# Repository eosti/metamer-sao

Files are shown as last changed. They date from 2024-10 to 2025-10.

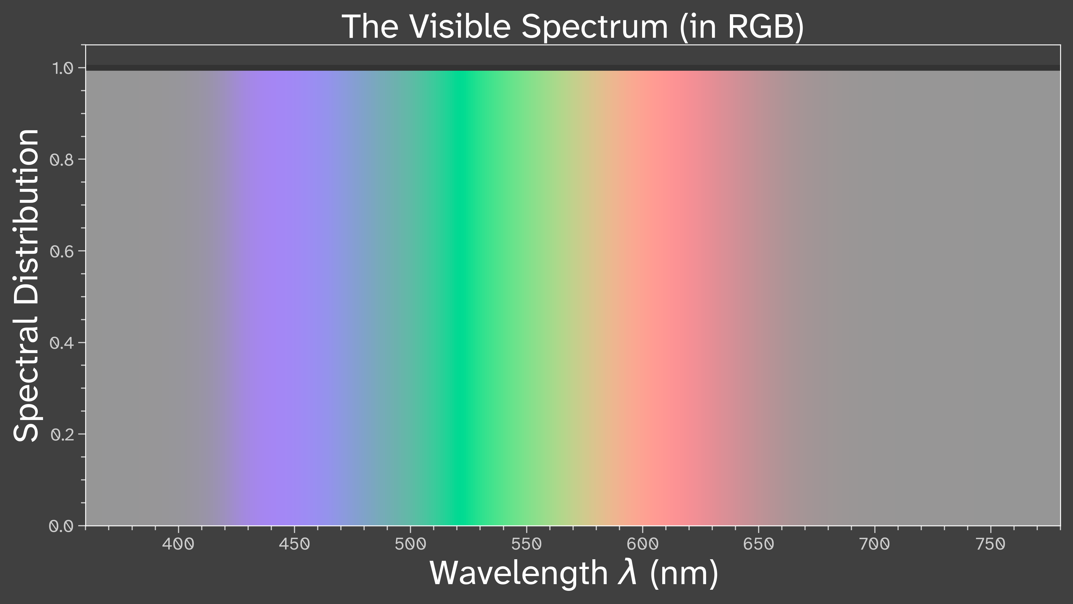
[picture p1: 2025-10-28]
python_graphs/visible_spectrum.png

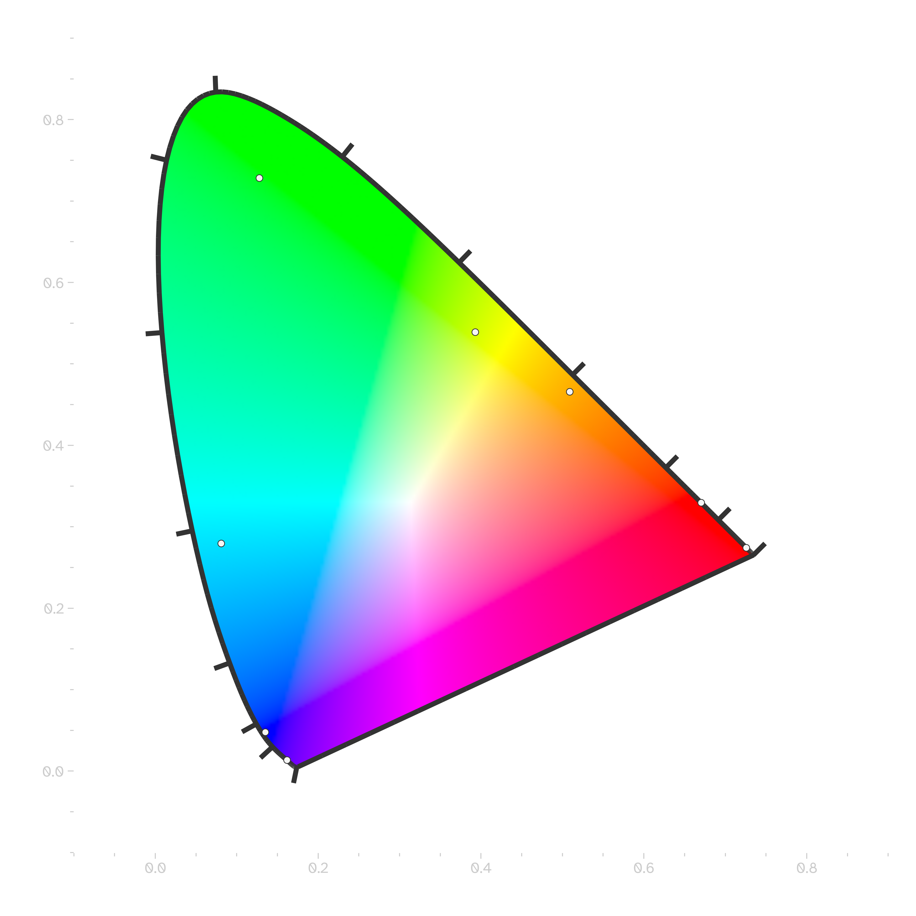
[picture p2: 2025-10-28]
python_graphs/build_cie1931.png

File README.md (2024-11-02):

# Metamer SAO
A collection of files related to the [Metamer SAO](https://reidsoxharris.me/projects/metamer-sao)

The `schematics` directory has PDFs of the schematics, the `board-files` directory has all the files you might need for fabrication and assembly including a BOM, and the `generators` directory contains the code used for auto-generating code for doing things like normalizing brightness. 

Some MicroPython code that you can run on the badge is found in the `micropython` directory. 
The code used on the PY32F002B MCU used to bootstrap I2C is in the `py32` directory, and current builds are in `py32/releases`.

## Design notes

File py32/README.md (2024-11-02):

# PY32
This is the code use for the bootstrap I2C MCU. 
It's the PY32F002B, so the cheapest one possible. 

The structure of the repo is largely taken from [py32f0-template](https://github.com/IOsetting/py32f0-template) -- I still don't know how Makefiles work, and that's okay. 
Building is as easy as `make`.

The version of the MCU code is stored in register 0x86. 

### Known Issues
On v0 firmware, the driver will be unable to communicate on I2C due to the MCU assuming the same address as the driver. 
In v1, the MCU will not only disable its own address, but also deinit the I2C peripheral after sending it's packet.
Problem solved!

The MCU will send a burst of I2C packets right at boot thay may conflict with other goings-ons on the bus. 
Theoretically, this should occur before the Pico on the badge is able to boot, but it's a shared bus and it's not the most considerate to other users on the bus to unexpectedly have a multi-master situation. 
If you run into any issues, a workaround is to cut off the I2C pins on the SAO connector: the SAO will still turn on as expected, but will not be controllable from the badge (obviously).

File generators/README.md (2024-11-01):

# Generators
i.e. code that generates other code! 

## generate_default_values
Quick script that parses a YAML file of LED specs and tries to come up with a normalizing array such that the brightness are the same. 

Emphasis on _tries_.
At present it assumes brightness scales with current (it does not) and that humans percieve all colors the same (we do not). 
But hey, it gets 95% of the way there, so that's good enough.

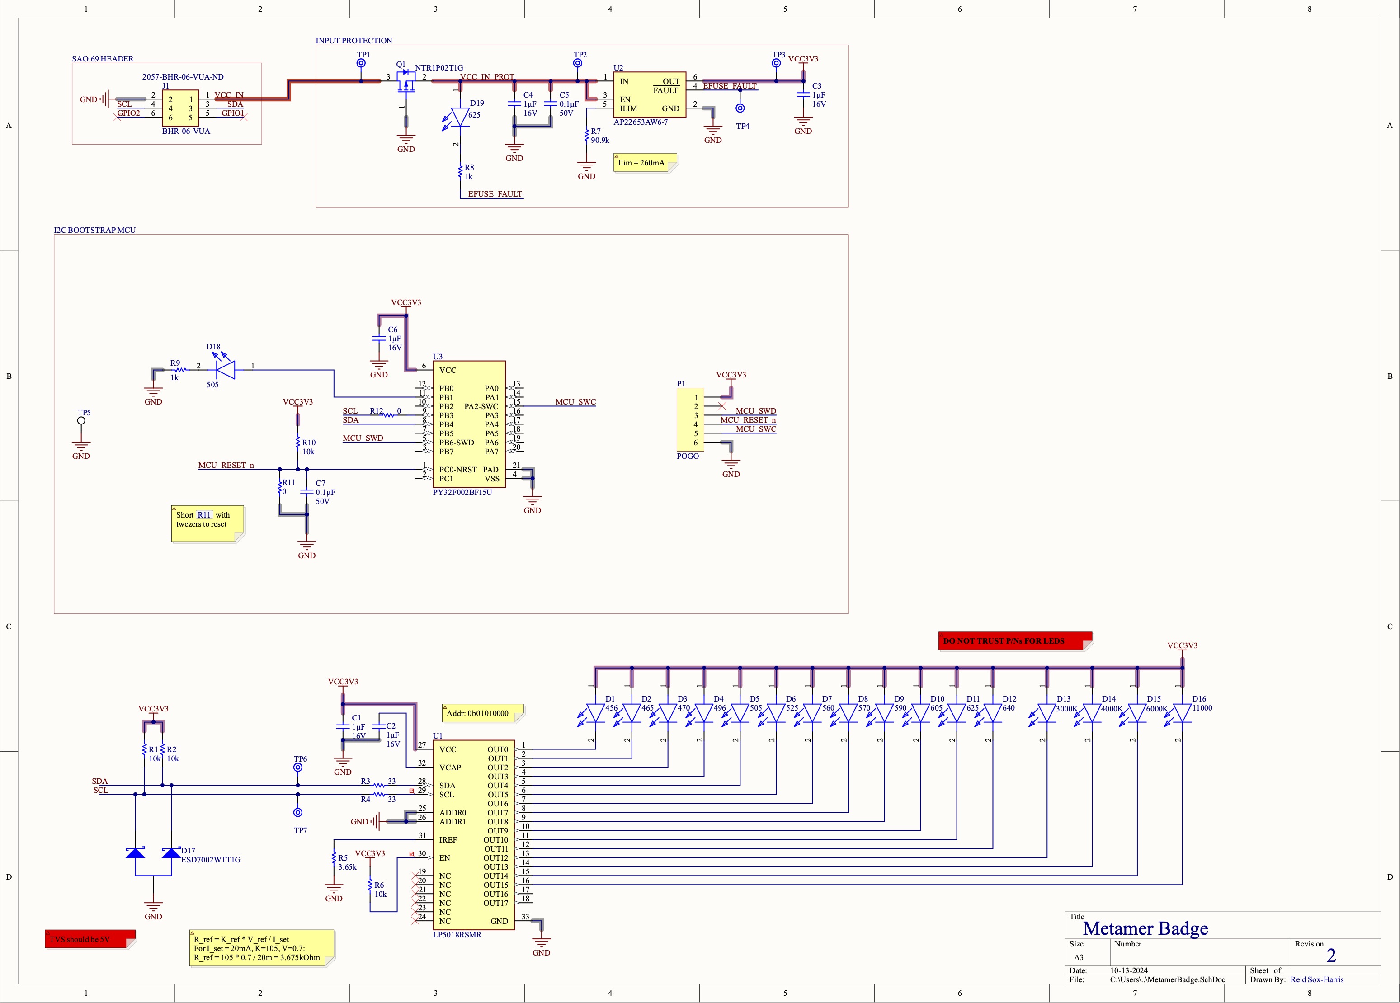
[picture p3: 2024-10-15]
schematics/metamerv2.jpg

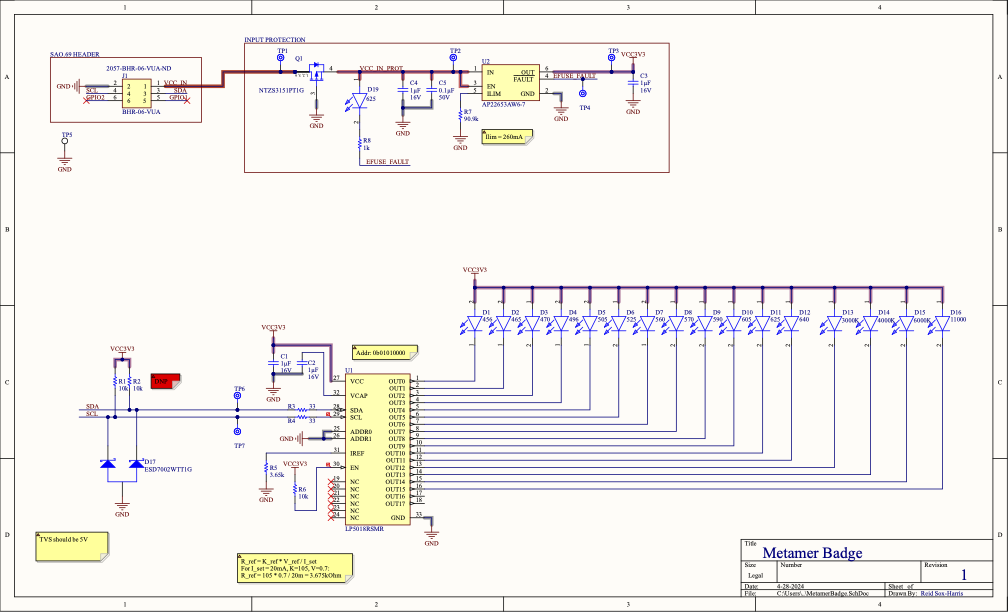
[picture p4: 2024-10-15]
schematics/Metamerv1.png

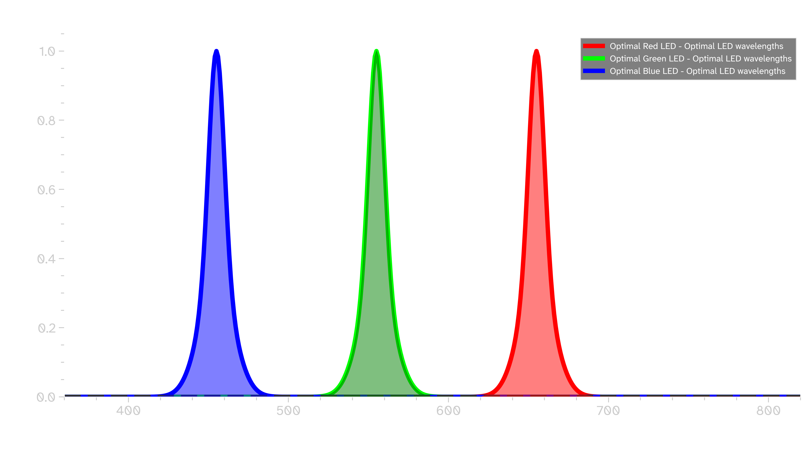
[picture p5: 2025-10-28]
python_graphs/ideal_leds.png

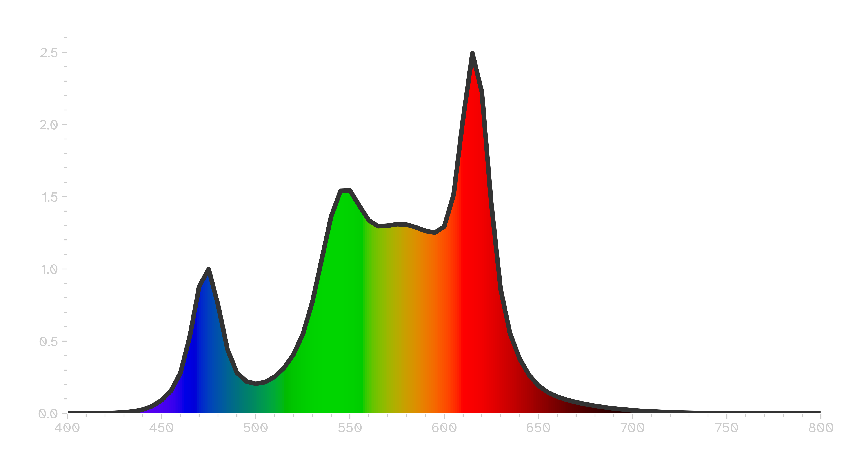
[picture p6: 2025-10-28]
python_graphs/lime_illuminant.png

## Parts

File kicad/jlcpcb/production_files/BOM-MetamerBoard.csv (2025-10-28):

Comment | Designator | Footprint | LCSC | Quantity
CGA3E1X7R1C105M080AC | C1,C2,C5 | C_0603 | C1588 | 3
CGA3E2X7R1H104K080AE | C4,C7 | C_0603 | C14663 | 2
CRCW060310K0FKEC | R1,R10,R2,R6,R7 | R_0603 | C25804 | 5
CRCW060333R0FKEA | R3,R4 | R_0603 | C23140 | 2
CRCW06033K65FKEA | R5 | R_0603 | C22980 | 1
ERJ-3EKF1001V | R9 | R_0603 | C21190 | 1
ERJ-3GEY0R00V | R11,R12,R8 | R_0603 | C21189 | 3
ESD7002WTT1G | D17 | SOT-23-3_L2.9-W1.5-P1.90-LS2.6-BR | C20615823 | 1
LP5018RSMR | U1 | FP-RSM0032B-MFG | C2891574 | 1
PY32F002BF15U | U3 | QFN-20-1EP_3x3mm_P0.4mm_EP1.65x1.65mm | C7469099 | 1
QBLP631-R | D18 | LED_0603_1608Metric_Pad1.05x0.95mm_HandSolder_SmallSilk | C2286 | 1
~ | C6 | C_0402 | C307331 | 1
~ | U2,U4 | SOT-363_SC-70-6 | C38663 | 2
QBLP661-IW5-CW | D16 | LED_0805_2012Metric_Pad1.15x1.40mm_HandSolder_SmallSilk |  | 1
QBLP631-S3 | D12 | LED_0805_2012Metric_Pad1.15x1.40mm_HandSolder_SmallSilk |  | 1
QBLP631-R | D11 | LED_0805_2012Metric_Pad1.15x1.40mm_HandSolder_SmallSilk |  | 1
QBLP631-O | D10 | LED_0805_2012Metric_Pad1.15x1.40mm_HandSolder_SmallSilk |  | 1
QBLP631-Y | D9 | LED_0805_2012Metric_Pad1.15x1.40mm_HandSolder_SmallSilk |  | 1
QBLP631-AG | D8 | LED_0805_2012Metric_Pad1.15x1.40mm_HandSolder_SmallSilk |  | 1
~ | D7 | LED_0805_2012Metric_Pad1.15x1.40mm_HandSolder_SmallSilk |  | 1
QBLP631-IG | D6 | LED_0805_2012Metric_Pad1.15x1.40mm_HandSolder_SmallSilk |  | 1
QBLP631-IB | D5 | LED_0603_1608Metric_Pad1.05x0.95mm_HandSolder_SmallSilk |  | 1
QBLP631-IB | D4 | LED_0603_1608Metric_Pad1.05x0.95mm_HandSolder_SmallSilk |  | 1
QBLP631-IB | D3 | LED_0805_2012Metric_Pad1.15x1.40mm_HandSolder_SmallSilk |  | 1
QBLP631-IB | D2 | LED_0805_2012Metric_Pad1.15x1.40mm_HandSolder_SmallSilk |  | 1
QBLP631-IB | D1 | LED_0805_2012Metric_Pad1.15x1.40mm_HandSolder_SmallSilk |  | 1
QBLP675-IW-NW | D14 | LED_SMD3012 |  | 1
QBLP675-IW-CW | D15 | LED_SMD3012 |  | 1
QBLP675-IW-WW | D13 | LED_SMD3012 |  | 1
BHR-06-VUA | J1 | SHDR6W64P254_2X3_1522X880X920P |  | 1

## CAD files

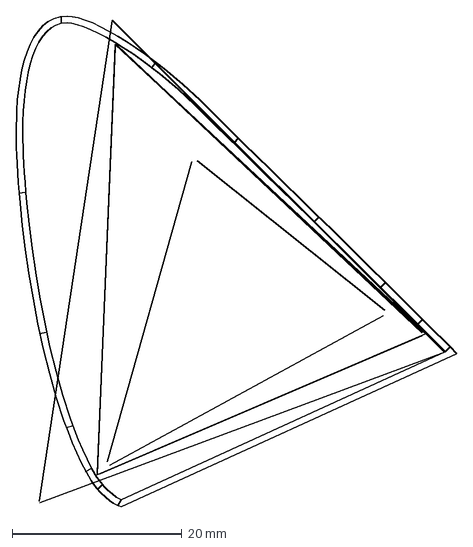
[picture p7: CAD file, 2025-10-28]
kicad/graphics/boardout.dxf
51.9 x 57.8 mm

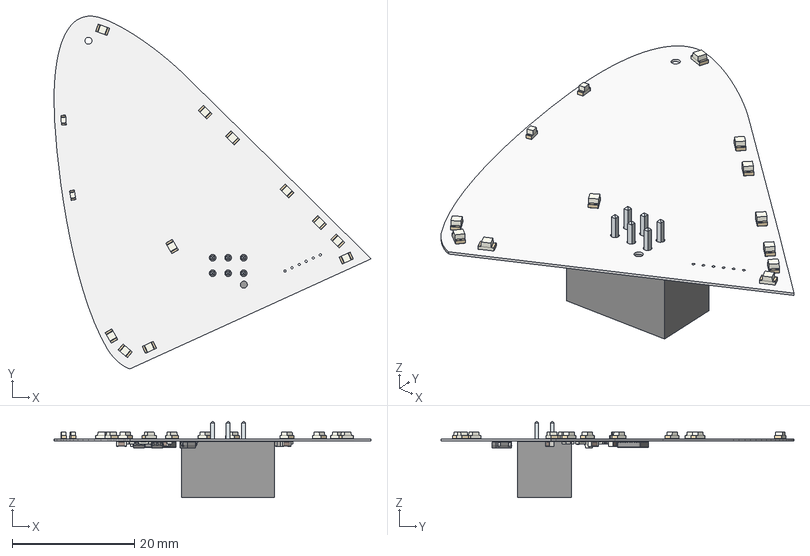
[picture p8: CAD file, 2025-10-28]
kicad/OUTPUTS/DOCS/.step
51.9 x 57.8 x 12.5 mm
LED_0603_1608Metric x 3
LED_0805_2012Metric x 11
C_0603 x 5
C_0402
R_0603 x 12
SOT-23-3_L2.9-W1.5-P1.90-LS2.6-BR
LeadsArray
SOT-363_SC-70-6 x 2
BODY-QFN
FRAME-RSM0032B
Texas Logo
Texas Logo - 1
MetamerBoard_PCB

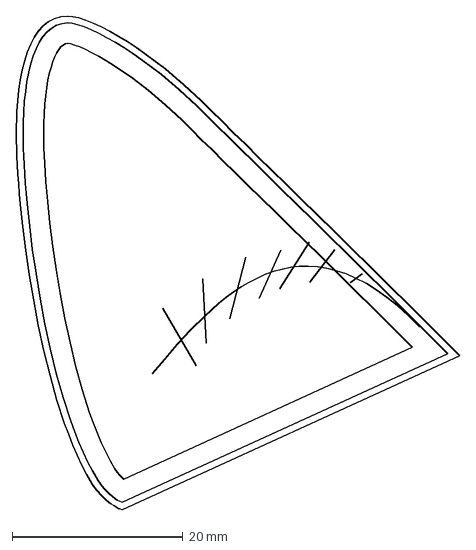
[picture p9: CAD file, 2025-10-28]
kicad/graphics/cie.dxf
51.9 x 57.8 mm

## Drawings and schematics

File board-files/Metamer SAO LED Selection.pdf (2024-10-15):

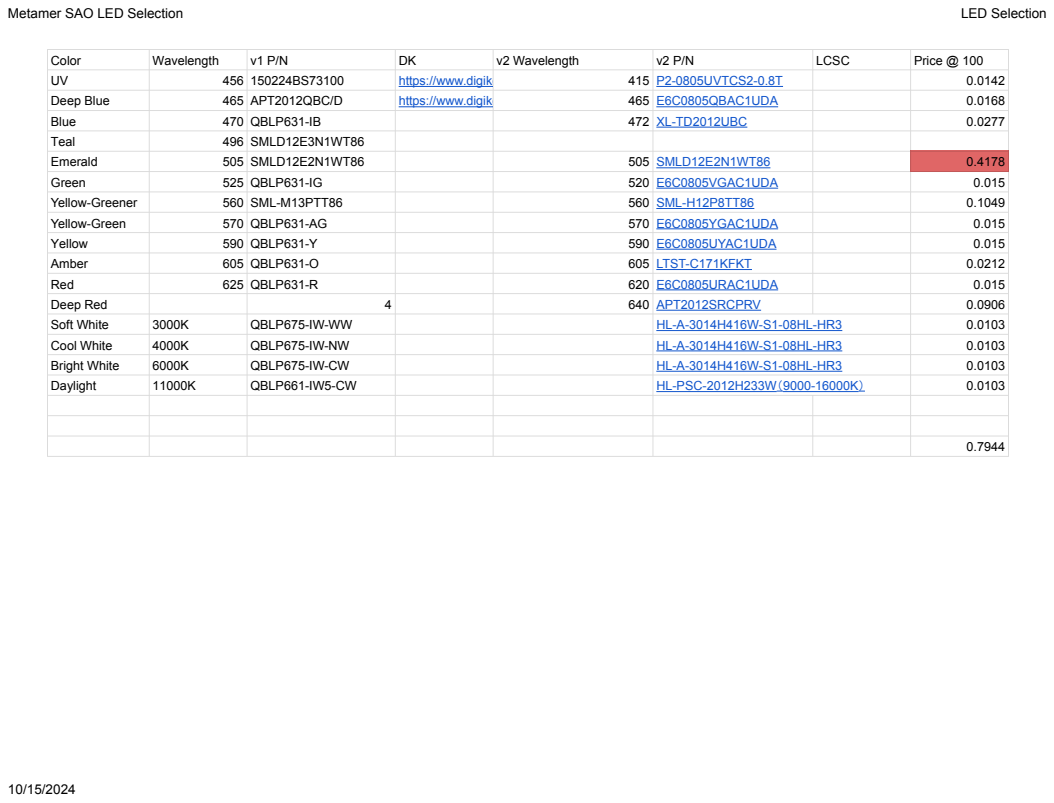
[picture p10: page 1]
Metamer SAO LED Selection; LED Selection; Color; Wavelength; v2 Wavelength; LCSC; Price @ 100; https://www.digikey.ca/en/products/detail/w%C3%BCrth-elektronik/150224BS73100/7315733 415 P2-0805UVTCS2-0.8T; Deep Blue; 465 APT2012QBC/D; https://www.digikey.ca/en/products/detail/kingbright/APT2012QBC-D/2163700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 465 E6C0805QBAC1UDA; Blue; 470 QBLP631-IB; 472 XL-TD2012UBC; Teal; 496 SMLD12E3N1WT86; Emerald; 505 SMLD12E2N1WT86; Green; 525 QBLP631-IG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

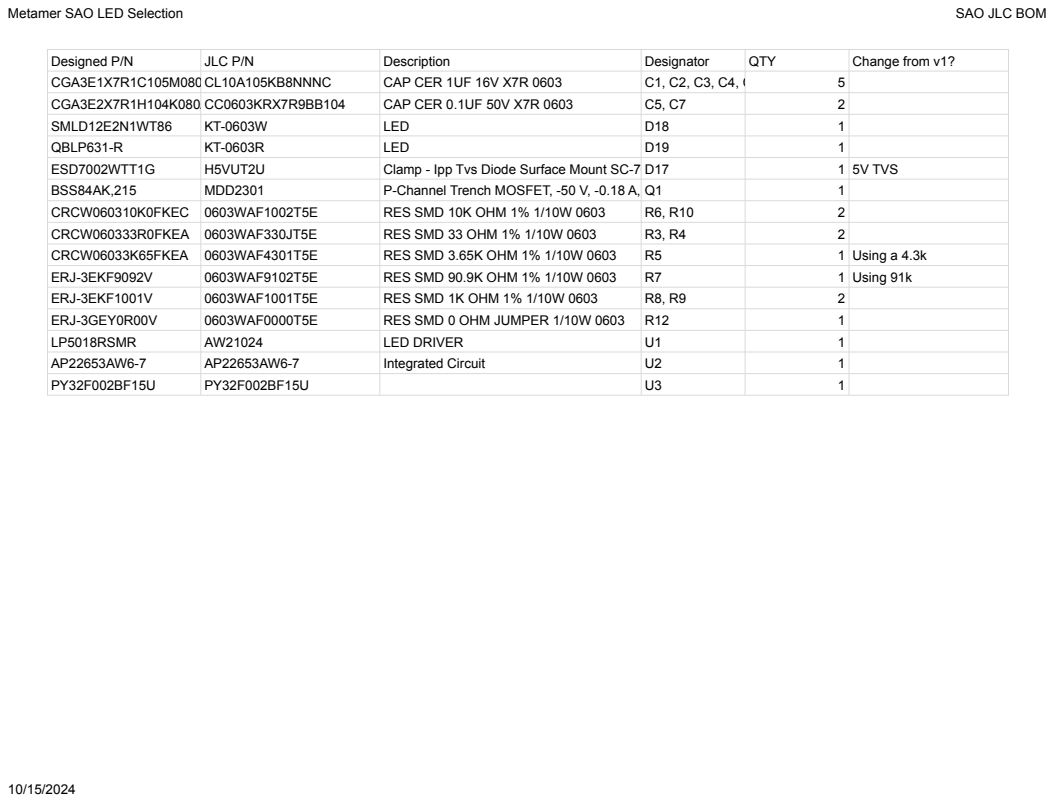
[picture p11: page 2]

Metamer SAO LED Selection | Debug Header

https://www.lcsc.com/product-detail/Pin-Headers_Samtec-FTSH-107-01-L-DV-K_C5307809.html

https://www.adafruit.com/product/2430#technical-details

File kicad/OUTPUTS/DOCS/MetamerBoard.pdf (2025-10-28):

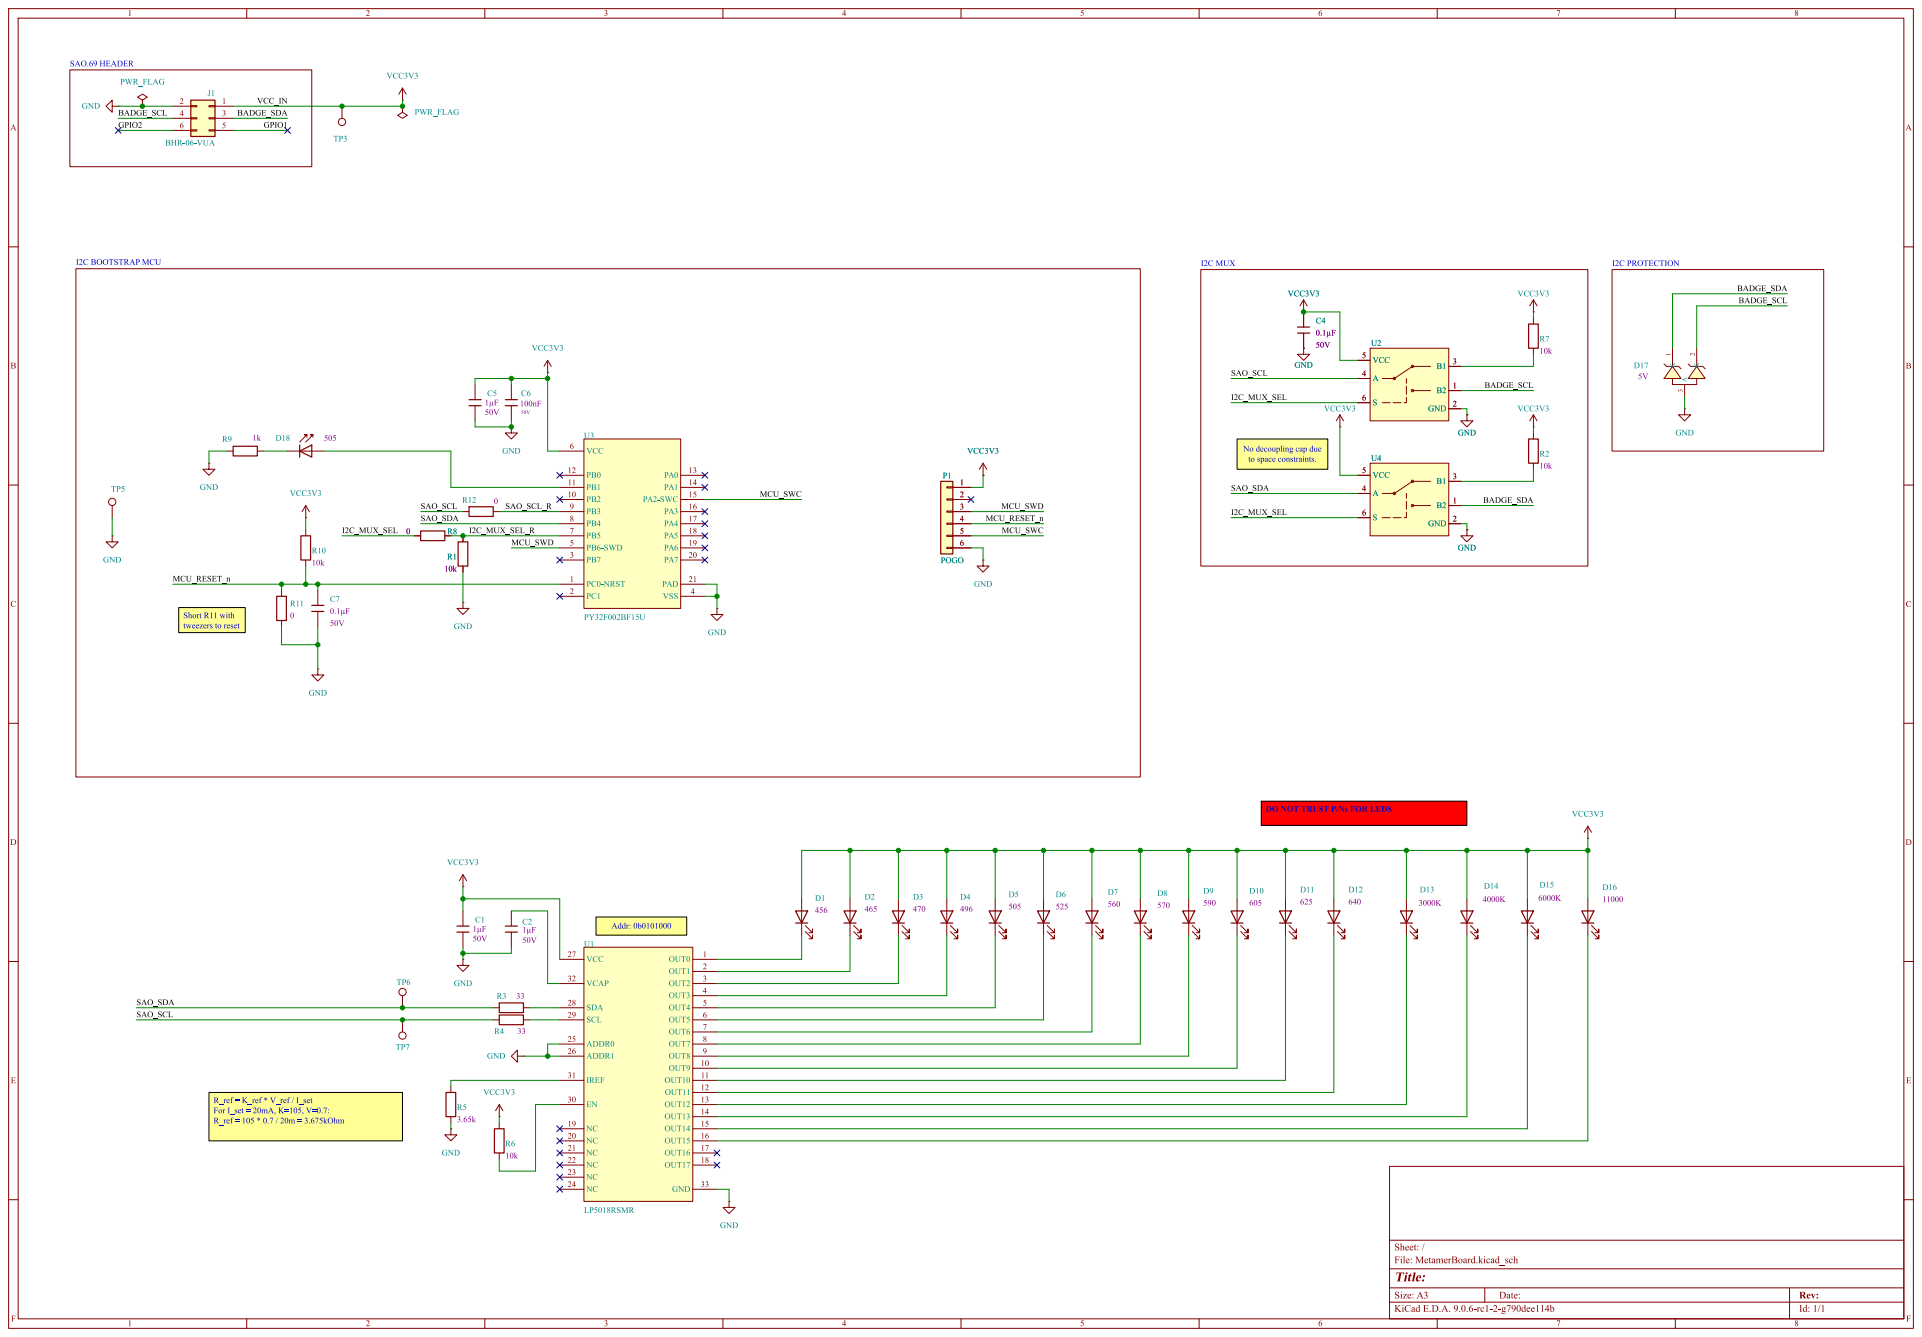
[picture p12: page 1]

10k VCC3V3 R7
to spaceconstraints. DO NOT TRUST P/NsFOR LEDS

Id: 1/1 Title: File: MetamerBoard.kicad_sch Sheet:/ GND

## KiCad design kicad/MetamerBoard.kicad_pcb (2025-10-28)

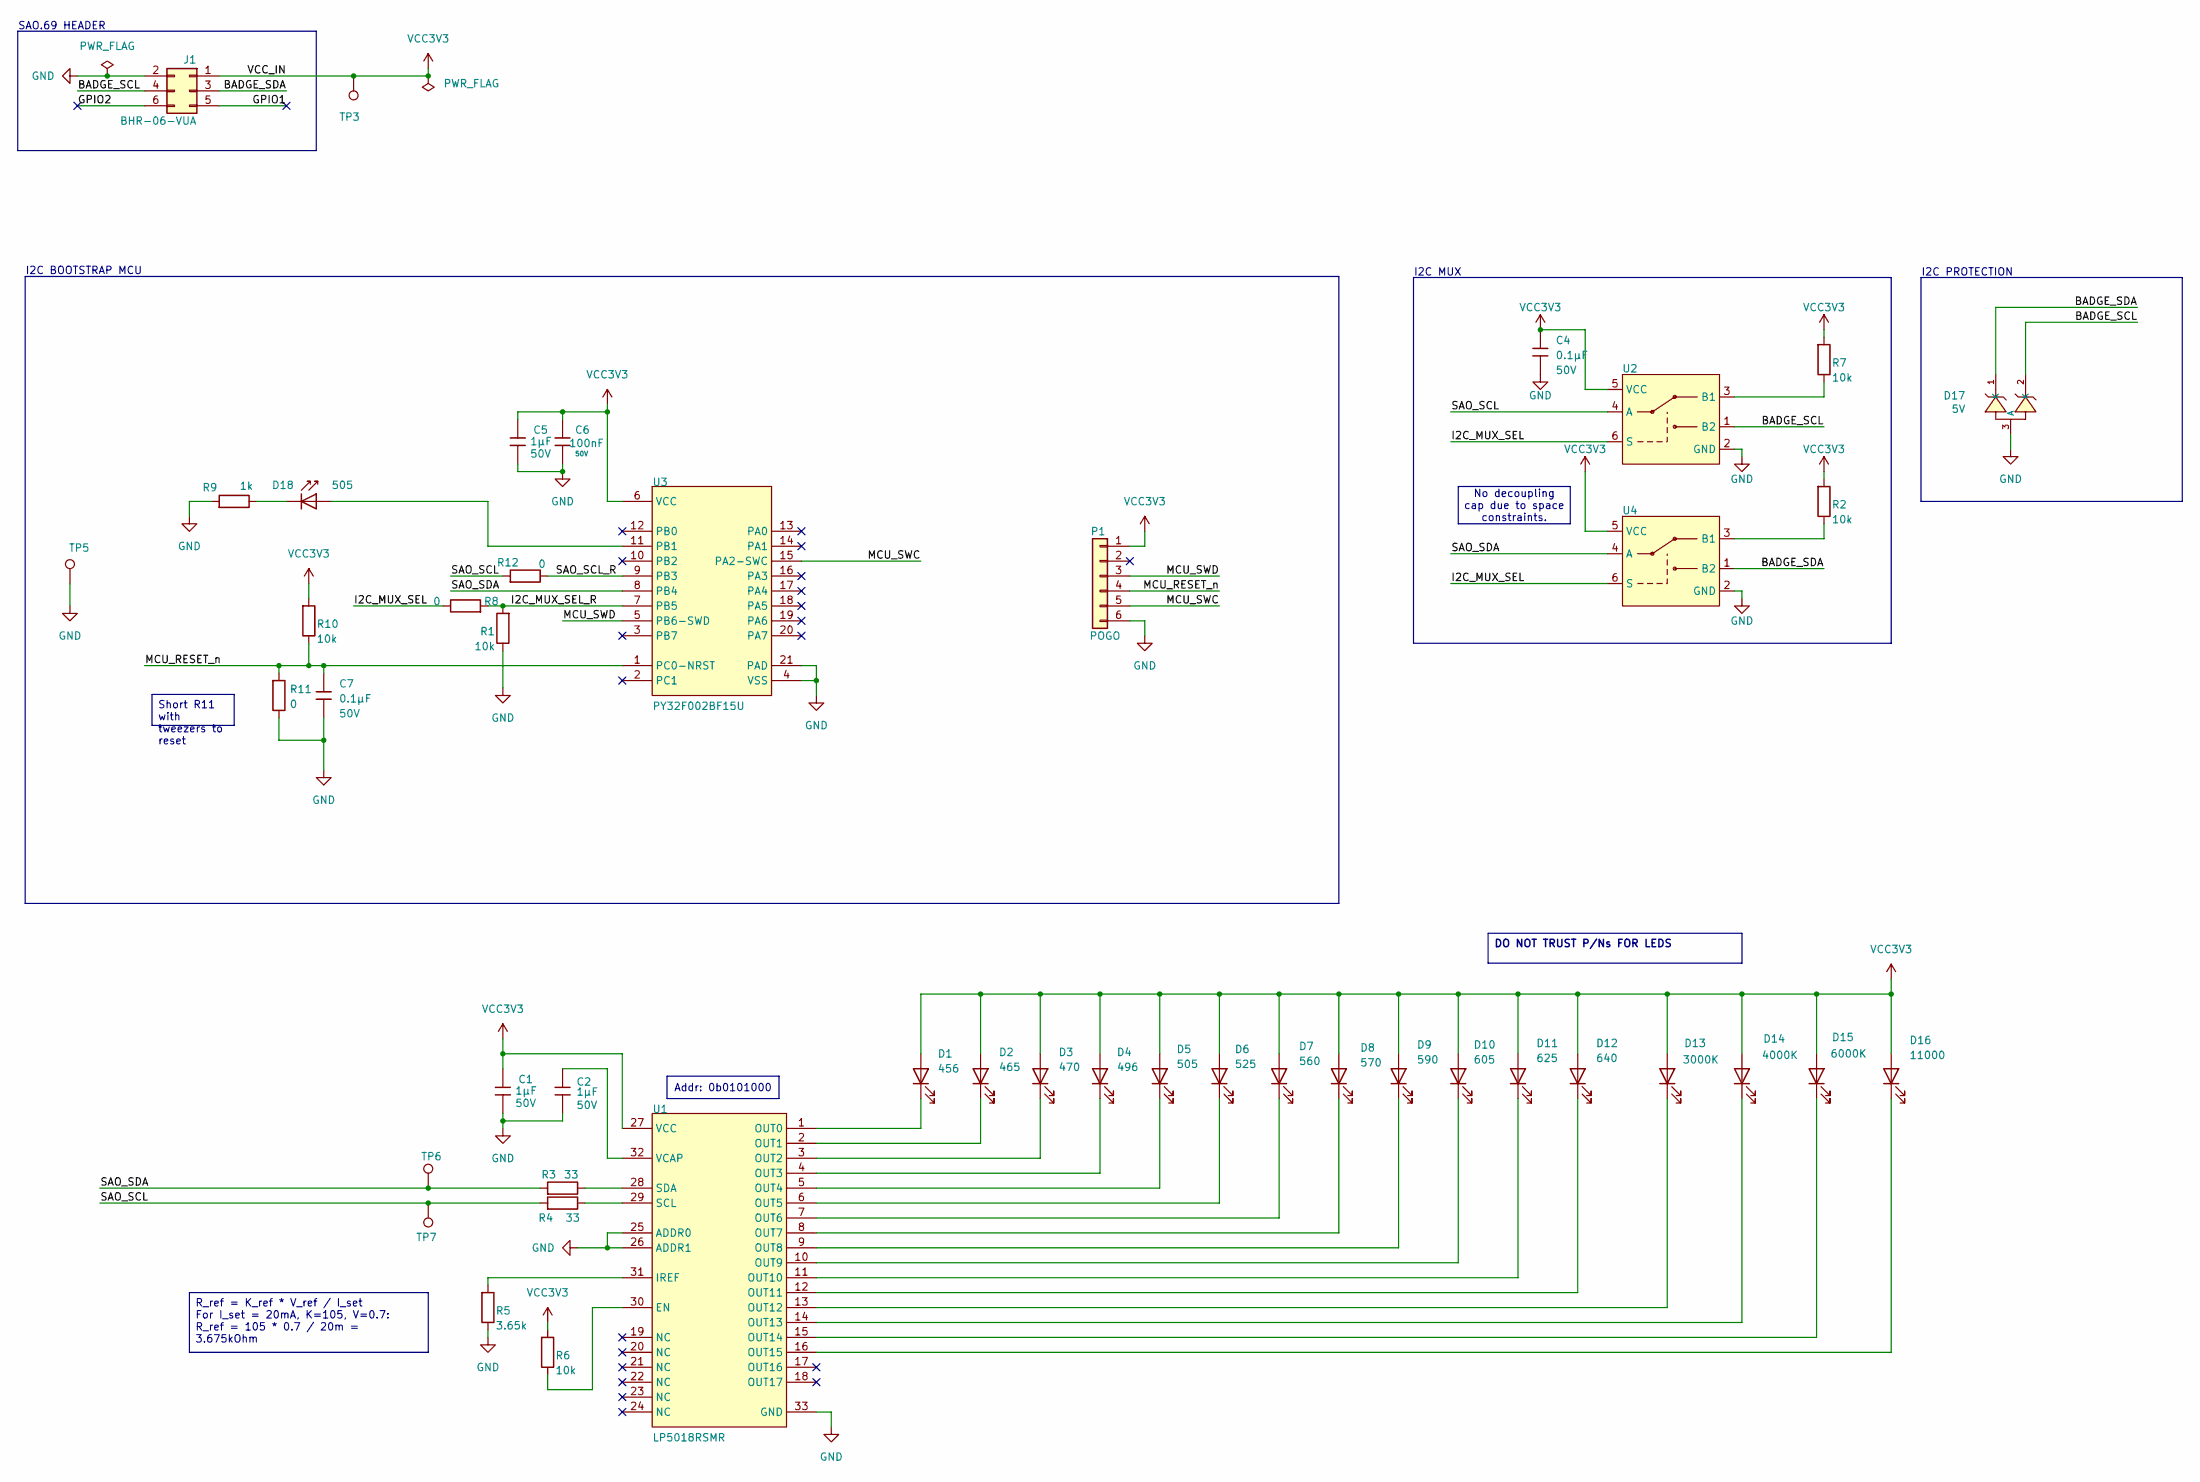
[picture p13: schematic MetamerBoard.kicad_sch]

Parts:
C1, C2, C5: CGA3E1X7R1C105M080AC; C_0603; TOLERANCE ±20%; RATINGS AEC-Q200; Part CL10B102KB8NNNC; LCSC C1588
C4, C7: CGA3E2X7R1H104K080AE; C_0603; TOLERANCE ±10%; VOLTAGE - RATED 50V; Part CC0603KRX7R9BB104; LCSC C14663
C6: C_0402; TOLERANCE ±20%; RATINGS AEC-Q200; Part CL05B104KB54PNC; LCSC C307331
D1, D2, D3: QBLP631-IB; LED_0805_2012Metric_Pad1.15x1.40mm_HandSolder_SmallSilk; MANUFACTURER_PART_NUMBER QBLP631-S3
D4, D5: QBLP631-IB; LED_0603_1608Metric_Pad1.05x0.95mm_HandSolder_SmallSilk; MANUFACTURER_PART_NUMBER QBLP631-S3
D6: QBLP631-IG; LED_0805_2012Metric_Pad1.15x1.40mm_HandSolder_SmallSilk; MANUFACTURER_PART_NUMBER QBLP631-S3
D7: LED_0805_2012Metric_Pad1.15x1.40mm_HandSolder_SmallSilk; MANUFACTURER_PART_NUMBER QBLP631-S3
D8: QBLP631-AG; LED_0805_2012Metric_Pad1.15x1.40mm_HandSolder_SmallSilk; MANUFACTURER_PART_NUMBER QBLP631-S3
D9: QBLP631-Y; LED_0805_2012Metric_Pad1.15x1.40mm_HandSolder_SmallSilk; MANUFACTURER_PART_NUMBER QBLP631-S3
D10: QBLP631-O; LED_0805_2012Metric_Pad1.15x1.40mm_HandSolder_SmallSilk
D11: QBLP631-R; LED_0805_2012Metric_Pad1.15x1.40mm_HandSolder_SmallSilk
D12: QBLP631-S3; LED_0805_2012Metric_Pad1.15x1.40mm_HandSolder_SmallSilk; MANUFACTURER_PART_NUMBER QBLP631-S3
D13: QBLP675-IW-WW; LED_SMD3012
D14: QBLP675-IW-NW; LED_SMD3012
D15: QBLP675-IW-CW; LED_SMD3012
D16: QBLP661-IW5-CW; LED_0805_2012Metric_Pad1.15x1.40mm_HandSolder_SmallSilk
D17: H5VHT2U; SOT-23-3_L2.9-W1.5-P1.90-LS2.6-BR; VOLTAGE - BREAKDOWN MIN 16.5V; VOLTAGE - REVERSE STAND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 5V; Part H5VHT2U; LCSC C20615823
D18: QBLP631-R; LED_0603_1608Metric_Pad1.05x0.95mm_HandSolder_SmallSilk; Part KT-0603R; LCSC C2286
J1: BHR-06-VUA; PinHeader_2x03_P2.54mm_Vertical; MANUFACTURER_PART_NUMBER BHR-06-VUA
P1: POGO; 6_Pin_POGO
R1, R2, R6, R7, R10: CRCW060310K0FKEC; R_0603; RATINGS AEC-Q200; TOLERANCE ±1%; Part 0603WAF1002T5E; LCSC C25804
R3, R4: CRCW060333R0FKEA; R_0603; RATINGS AEC-Q200; TOLERANCE ±1%; Part 0603WAF330JT5E; LCSC C23140
R5: CRCW06033K65FKEA; R_0603; TOLERANCE ±1%; RATINGS AEC-Q200; Part 0603WAF3601T5E; LCSC C22980
R8, R11, R12: ERJ-3GEY0R00V; R_0603; RATINGS AEC-Q200; TOLERANCE Jumper; Part 0603WAF0000T5E; LCSC C21189
R9: ERJ-3EKF1001V; R_0603; RATINGS AEC-Q200; TOLERANCE ±1%; Part 0603WAF1001T5E; LCSC C21190
TP3, TP6, TP7: TPAD10R; TestPoint_Pad_D1.0mm
TP5: 5019; TestPoint_Keystone_5019_Miniature
U1: LP5018RSMR; VQFN-32-1EP_4x4mm_P0.4mm_EP2.8x2.8mm; OUTPUT VOLTAGE 5.5V; MANUFACTURER PART NUMBER LP5018RSMR; DIGIKEY DESCRIPTION LED DRIVER
U2, U4: SOT-363_SC-70-6
U3: PY32F002BF15U; QFN-20-1EP_3x3mm_P0.4mm_EP1.65x1.65mm

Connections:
/BADGE_SCL: D17.2 (K), J1.4, U2.1 (B2)
/BADGE_SDA: D17.1 (K), J1.3, U4.1 (B2)
/GPIO1: J1.5
/GPIO2: J1.6
/I2C_MUX_SEL: R8.2, U2.6 (S), U4.6 (S)
/I2C_MUX_SEL_R: R1.1, R8.1, U3.7 (PB5)
/MCU_RESET_n: C7.1, P1.4, R10.2, R11.1, U3.1 (PC0-NRST)
/MCU_SWC: P1.5, U3.15 (PA2-SWC)
/MCU_SWD: P1.3, U3.5 (PB6-SWD)
/SAO_SCL: R4.1, R12.1, TP7.1, U2.4 (A)
/SAO_SCL_R: R12.2, U3.9 (PB3)
/SAO_SDA: R3.1, TP6.1, U3.8 (PB4), U4.4 (A)
GND: C1.2, C2.2, C4.2, C5.2, C6.2, C7.2, D17.3 (A), J1.2, P1.6, R1.2, R5.2, R9.1, R11.2, TP5.1, U1.25 (ADDR0), U1.26 (ADDR1), U1.33 (GND), U2.2 (GND), U3.4 (VSS), U3.21 (PAD), U4.2 (GND)
unnamed: D1.1 (K), U1.1 (OUT0)
unnamed: D2.1 (K), U1.2 (OUT1)
unnamed: D3.1 (K), U1.3 (OUT2)
unnamed: D4.1 (K), U1.4 (OUT3)
unnamed: D5.1 (K), U1.5 (OUT4)
unnamed: D6.1 (K), U1.6 (OUT5)
unnamed: D7.1 (K), U1.7 (OUT6)
unnamed: D8.1 (K), U1.8 (OUT7)
unnamed: D9.1 (K), U1.9 (OUT8)
unnamed: D10.1 (K), U1.10 (OUT9)
unnamed: D11.1 (K), U1.11 (OUT10)
unnamed: D12.1 (K), U1.12 (OUT11)
unnamed: D13.1 (K), U1.13 (OUT12)
unnamed: D14.1 (K), U1.14 (OUT13)
unnamed: D15.1 (K), U1.15 (OUT14)
unnamed: D16.1 (K), U1.16 (OUT15)
unnamed: D18.1, R9.2
unnamed: R6.2, U1.30 (EN)
unnamed: R5.1, U1.31 (IREF)
unnamed: R4.2, U1.29 (SCL)
unnamed: R3.2, U1.28 (SDA)
unnamed: C2.1, U1.32 (VCAP)
unnamed: R7.2, U2.3 (B1)
unnamed: D18.2, U3.11 (PB1)
unnamed: R2.2, U4.3 (B1)
VCC3V3: C1.1, C4.1, C5.1, C6.1, D1.2 (A), D2.2 (A), D3.2 (A), D4.2 (A), D5.2 (A), D6.2 (A), D7.2 (A), D8.2 (A), D9.2 (A), D10.2 (A), D11.2 (A), D12.2 (A), D13.2 (A), D14.2 (A), D15.2 (A), D16.2 (A), J1.1, P1.1, R2.1, R6.1, R7.1, R10.1, TP3.1, U1.27 (VCC), U2.5 (VCC), U3.6 (VCC), U4.5 (VCC)

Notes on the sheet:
SAO.69 HEADER
I2C BOOTSTRAP MCU
I2C MUX
I2C PROTECTION
DO NOT TRUST P/Ns FOR LEDS
Short R11 with tweezers to reset
R_ref = K_ref * V_ref / I_set For I_set = 20mA, K=105, V=0.7: R_ref = 105 * 0.7 / 20m = 3.675kOhm
Addr: 0b0101000
No decoupling cap due to space constraints.

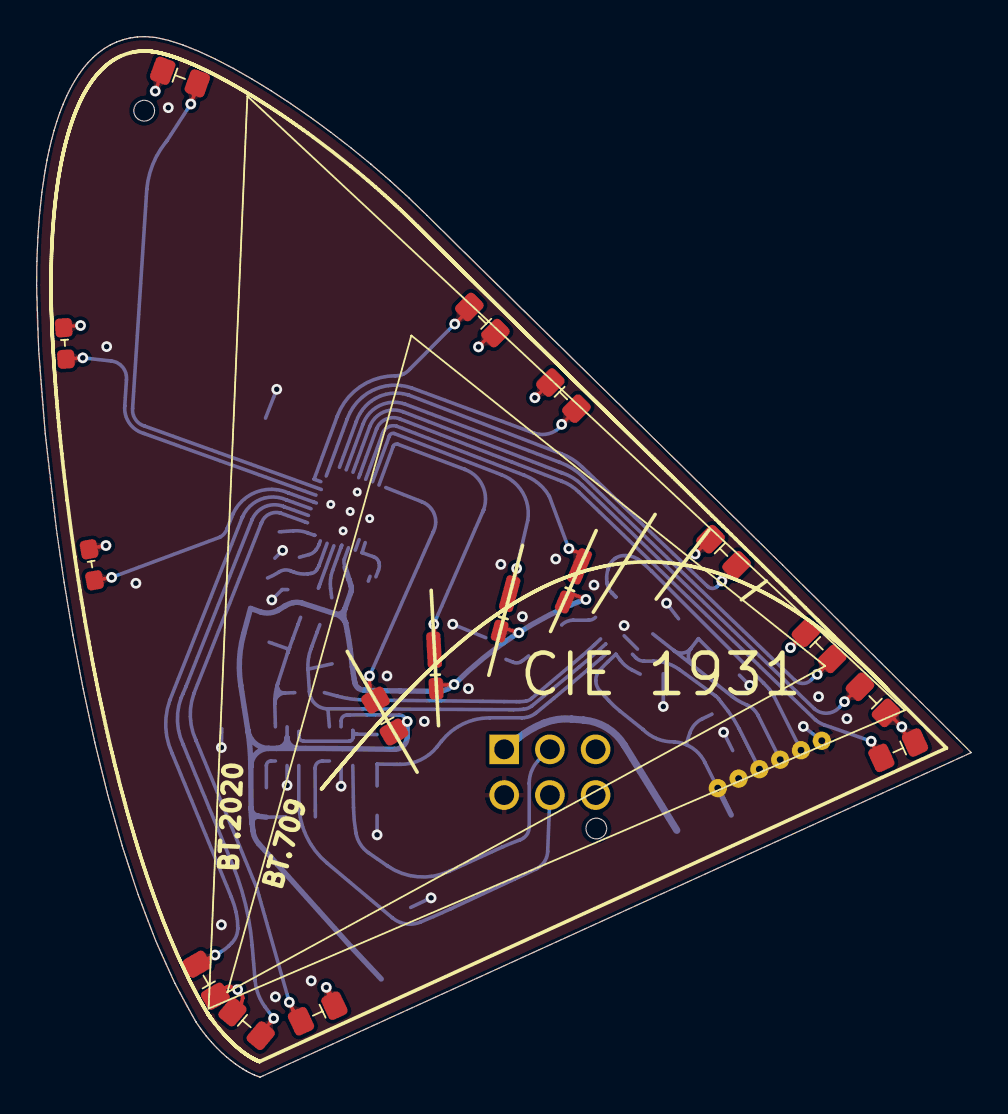
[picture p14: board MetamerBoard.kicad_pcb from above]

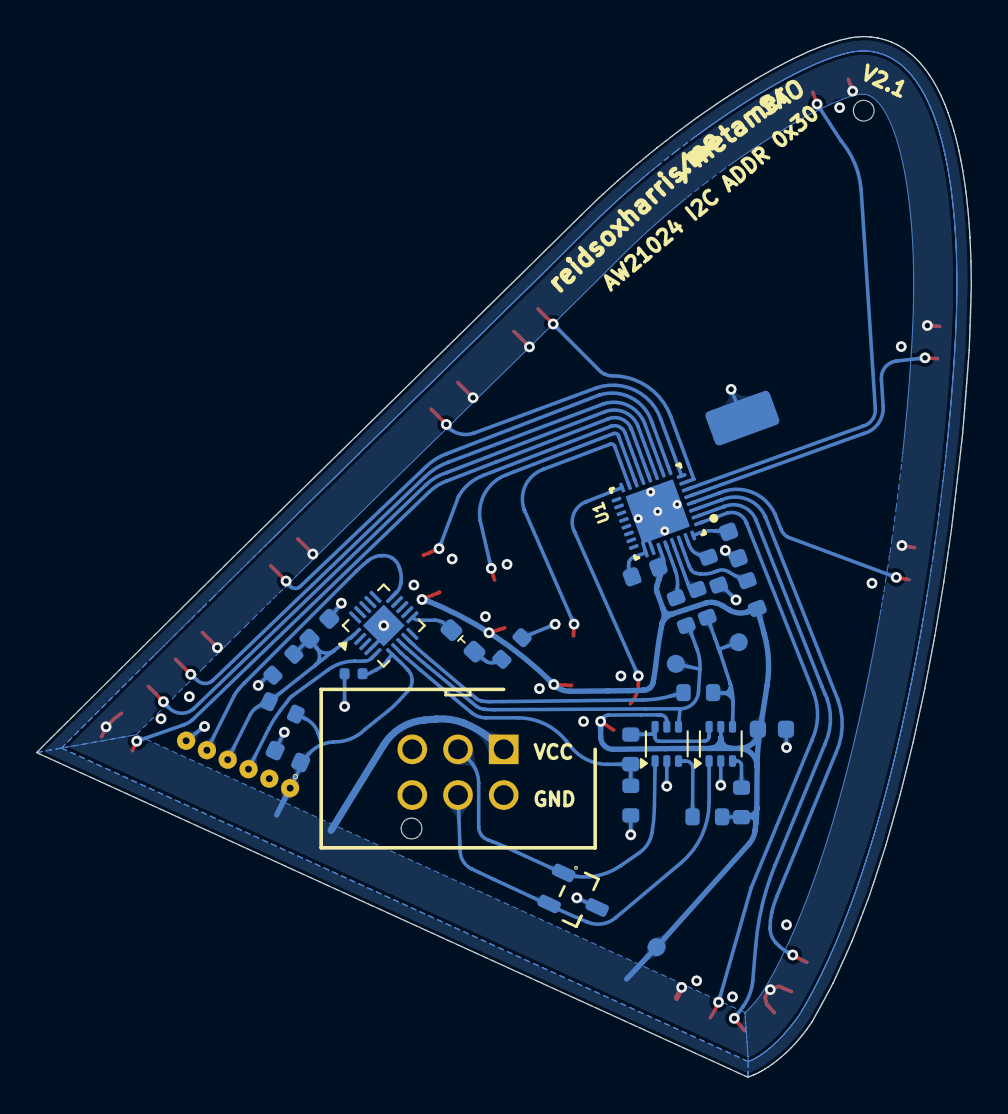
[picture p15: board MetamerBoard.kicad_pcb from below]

Board: 2 copper layers, 51.9 x 57.8 mm, 46 parts (30 on the bottom side), 37 nets.

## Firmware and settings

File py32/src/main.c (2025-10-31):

#include "main.h"

// TODO:  add a dummy register marker to show MCU code version
//        Linting, formatting
//        Documentation
//        PWM for LED?

#define VERSION_NUMBER 0x02

I2C_HandleTypeDef hi2c;

static void HAL_I2CConfig(void);
static void HAL_GpioConfig(void);
inline static void aw210xx_write(uint8_t reg, uint8_t val);
void ErrorHandler(void);

/**
 * @brief  The main function!
 * @retval int
 */
int main(void) {
    HAL_Init();
    HAL_I2CConfig();
    HAL_GpioConfig();

    // Starting config is local I2C
    HAL_GPIO_WritePin(I2C_MUX_PORT, I2C_MUX_PIN, GPIO_PIN_RESET);
    HAL_GPIO_WritePin(LED_GPIO_PORT, LED_GPIO_PIN, GPIO_PIN_SET);

    // GCR = 0x01 (chip enable)
    aw210xx_write(0x00, 0x01);
    // GCCR = 0xFF (max global current)
    aw210xx_write(0x6E, 0xFF);

    uint8_t default_values[] = {6, 11, 11, 12, 9, 2, 255, 34, 11, 12, 10, 11, 1, 1, 1, 1, 0, 0};
    for (int i = 0; i < 16; i++) {
        // BRn = default_values[i] (scaled brightness)
        aw210xx_write(0x01 + i, default_values[i]);
        // COLn = 0xFF (max channel current)
        aw210xx_write(0x4A + i, 0xFF);
    }

    // UPDATE = 0x00 (update)
    aw210xx_write(0x49, 0x00);

    // GBRH = VERSION
    // Misusing a register for the badge to determine MCU code version
    aw210xx_write(0x86, VERSION_NUMBER);

    HAL_I2C_DeInit(&hi2c);

    // Once bootstrapped, connect I2C bus to badge
    HAL_GPIO_WritePin(I2C_MUX_PORT, I2C_MUX_PIN, GPIO_PIN_SET);
    HAL_GPIO_WritePin(LED_GPIO_PORT, LED_GPIO_PIN, GPIO_PIN_RESET);

    while (1) {
        // nop
    }
}

/**
 * @brief Configures the GPIO
 */
static void HAL_GpioConfig(void) {
    GPIO_InitTypeDef GPIO_InitStruct;

    __HAL_RCC_GPIOB_CLK_ENABLE(); /* Enable GPIOA clock */

    // PB1 -> white status LED
    GPIO_InitStruct.Pin   = LED_GPIO_PIN;
    GPIO_InitStruct.Mode  = GPIO_MODE_OUTPUT_PP;  /* Push-pull output */
    GPIO_InitStruct.Pull  = GPIO_PULLUP;          /* Enable pull-up */
    GPIO_InitStruct.Speed = GPIO_SPEED_FREQ_HIGH; /* GPIO speed */
    HAL_GPIO_Init(LED_GPIO_PORT, &GPIO_InitStruct);
    //
    // PB5 -> I2C mux pin (0 = local I2C, 1 = badge I2C)
    GPIO_InitStruct.Pin   = I2C_MUX_PIN;
    GPIO_InitStruct.Mode  = GPIO_MODE_OUTPUT_PP;  /* Push-pull output */
    GPIO_InitStruct.Pull  = GPIO_PULLDOWN;        /* Enable pull-down */
    GPIO_InitStruct.Speed = GPIO_SPEED_FREQ_HIGH; /* GPIO speed */
    HAL_GPIO_Init(I2C_MUX_PORT, &GPIO_InitStruct);
}

/**
 * @brief Configures the I2C peripheral
 */
static void HAL_I2CConfig(void) {
    hi2c.Instance             = I2C;
    hi2c.Init.ClockSpeed      = I2C_CLOCKSPEED;
    hi2c.Init.DutyCycle       = I2C_DUTYCYCLE_16_9;
    hi2c.Init.OwnAddress1     = 0;
    hi2c.Init.GeneralCallMode = I2C_GENERALCALL_DISABLE;
    hi2c.Init.NoStretchMode   = I2C_NOSTRETCH_DISABLE;

    if (HAL_I2C_Init(&hi2c) != HAL_OK) { ErrorHandler(); }
}

/**
 * @brief  helper to write to the AW210XX
 */
inline static void aw210xx_write(uint8_t reg, uint8_t val) {
    if (HAL_I2C_Mem_Write(&hi2c, AW210XX_ADDRESS << 1, reg, I2C_MEMADD_SIZE_8BIT, &val, 1, 1000) != HAL_OK) {
        ErrorHandler();
    }
}

/**
 * @brief  Error executing function.
 */
void ErrorHandler(void) {
    while (1) {
        // Flashing LED = something went wrong
        HAL_GPIO_TogglePin(LED_GPIO_PORT, LED_GPIO_PIN);
        HAL_Delay(500);
    }
}

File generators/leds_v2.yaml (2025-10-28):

# bandwidth values are a bit messy because most are derived from graph
global:
  i2c_address: 0x48 # 7-bit
  r_ext: 3650
leds:
  - name: Deep Red
    pn: APT2012SRCPRV
    test_current_ma: 20
    max_current_ma: 30
    wavelength_dominant: 640
    wavelength_peak: 655
    bandwidth: 20
    brightness_mcd: 100
    index: 11
  - name: Red
    pn: E6C0805URAC1UDA
    test_current_ma: 20
    max_current_ma: 30
    wavelength_dominant: 620
    bandwidth: 20
    brightness_mcd: 110
    index: 10
  - name: Orange
    pn: LTST-C171KFKT 
    test_current_ma: 20
    max_current_ma: 30
    wavelength_dominant: 605
    wavelength_peak: 611
    bandwidth: 17
    brightness_mcd: 90
    index: 9
  - name: Yellow
    pn: E6C0805UYAC1UDA
    test_current_ma: 20
    max_current_ma: 25
    wavelength_dominant: 590
    wavelength_peak: 591
    bandwidth: 15
    brightness_mcd: 100
    index: 8
  - name: Yellow Green
    pn: E6C0805YGAC1UDA
    test_current_ma: 20
    max_current_ma: 25
    wavelength_dominant: 570
    wavelength_peak: 573
    bandwidth: 15
    brightness_mcd: 30
    index: 7
  - name: Green
    pn: SML-H12P8TT86
    test_current_ma: 20
    max_current_ma: 20
    wavelength_dominant: 560
    bandwidth: 17
    brightness_mcd: 4
    index: 6
  - name: True Green
    pn: E6C0805VGAC1UDA
    test_current_ma: 20
    max_current_ma: 25
    wavelength_dominant: 525
    wavelength_peak: 518
    bandwidth: 17
    brightness_mcd: 600
    index: 5
  - name: Blue Greener
    pn: SMLD12E2N1WT86
    test_current_ma: 5
    max_current_ma: 20
    wavelength_dominant: 505
    bandwidth: 12
    brightness_mcd: 120
    index: 4
  - name: Bluer Green
    pn: SMLD12E3N1WT86
    test_current_ma: 5
    max_current_ma: 20
    wavelength_dominant: 496
    bandwidth: 12
    brightness_mcd: 85
    index: 3
  - name: Blue
    pn: XL-TD2012UBC 
    test_current_ma: 20
    max_current_ma: 20
    wavelength_dominant: 470
    wavelength_peak: 470
    bandwidth: 12
    # altered to fudge the values
    brightness_mcd: 100
    index: 2
  - name: Bluer
    pn: E6C0805QBAC1UDA
    test_current_ma: 20
    max_current_ma: 25
    wavelength_dominant: 465
    wavelength_peak: 465
    bandwidth: 12
    brightness_mcd: 100
    index: 1
  - name: UV
    pn: P2-0805UVTCS2-0.8T 
    test_current_ma: 20
    max_current_ma: 30
    wavelength_dominant: 405
    wavelength_peak: 405
    bandwidth: 13
    # altered to fudge the values (fudge to 200)
    brightness_mcd: 50
    index: 0
  - name: Daylight White (11000K)
    pn: HL-PSC-2012H233W 9000-16000
    test_current_ma: 20
    max_current_ma: 30
    color_temperature: 11000
    brightness_mcd: 1300
    index: 15
  - name: Bright White (6000K)
    pn: HL-A-3014H416W-S1-08HL-HR3 
    test_current_ma: 30
    max_current_ma: 40
    color_temperature: 6000
    brightness_mcd: 4300
    index: 14
  - name: Cool White (4000K)
    pn: HL-A-3014H416W-S1-08HL-HR3 
    test_current_ma: 30
    max_current_ma: 40
    color_temperature: 4000
    brightness_mcd: 4300
    index: 13
  - name: Warm White (3000K)
    pn: HL-A-3014H416W-S1-08HL-HR3 
    test_current_ma: 30
    max_current_ma: 40
    color_temperature: 3000
    brightness_mcd: 4000
    index: 12

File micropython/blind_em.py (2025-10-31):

# Turns all the LEDs on all the way. Because you can.

from machine import I2C, Pin

from aw210xx import AW210xx


def main():
    i2c = I2C(0, scl=Pin(1), sda=Pin(0), freq=100000)
    print(i2c.scan())
    leds = AW210xx(i2c, r_ext=3650, model="AW21024")

    leds.reset()
    leds.chip_enabled(True)
    print(
        f"Driver ID: 0x{leds.get_id():02X}, Driver Version: 0x{leds.get_version():02X}"
    )
    leds.global_current(255)

    for i in range(16):
        leds.br(i, 255)
        leds.col(i, 255)

    leds.update()


if __name__ == "__main__":
    main()

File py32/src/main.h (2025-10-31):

#ifndef __MAIN_H
#define __MAIN_H

#ifdef __cplusplus
extern "C" {
#endif

// Includes
#include "py32f002b_hal.h"

// SAO Defines
#define LED_GPIO_PIN    GPIO_PIN_1
#define LED_GPIO_PORT   GPIOB
#define I2C_CLOCKSPEED  100000
#define AW210XX_ADDRESS 0x30

#define I2C_MUX_PIN GPIO_PIN_5
#define I2C_MUX_PORT GPIOB

// Exports
extern I2C_HandleTypeDef hi2c;

#ifdef __cplusplus
}
#endif

#endif

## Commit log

2024-11-02 fix i2c address aliasing
    [main.c, py32f002b_hal_msp.c]
2025-10-28 add v2.1 files
    [.step, BOM-MetamerBoard.csv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]
